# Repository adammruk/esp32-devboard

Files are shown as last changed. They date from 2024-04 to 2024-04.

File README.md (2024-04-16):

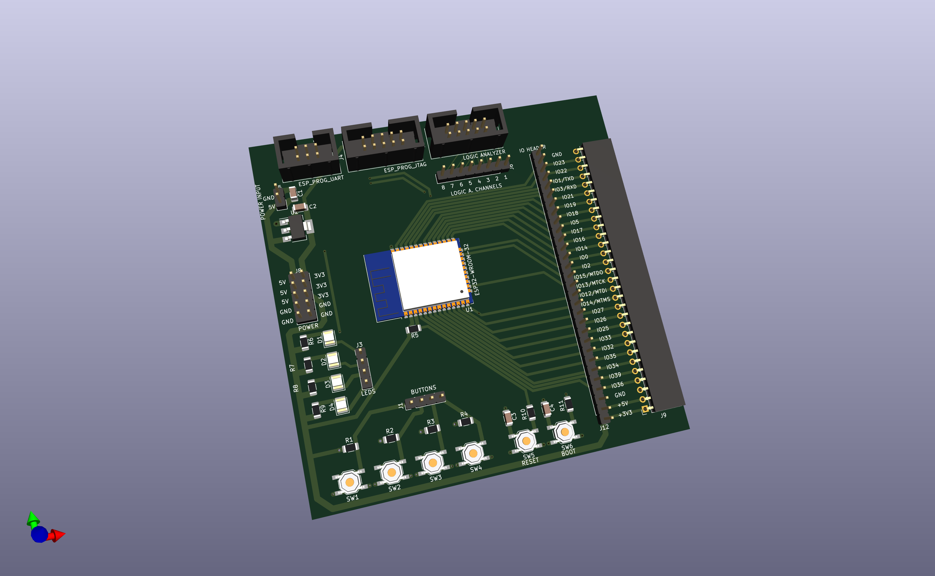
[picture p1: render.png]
ESP32 Development Board


# ESP32 Development Board

## Why a new development board?

Currently, there are many different development boards for ESP32 available on the market. I have also been using various different ones - ESP32-Cam, ESP32 WROOM, ESP32 WROOM on a board with buttons, MicroUSB port, and GPIO ports, ESP32 module with an LCD display, etc. Every board has some nice features, but overall I have always been missing the things that I believe a dev board should have:

- easy access to GPIO; most of the boards have a really inconvenient access to GPIO pins, making it harder to connect/disconnect cables
- properly described microcontroller pins, especially GPIO. This is the thing that widely used boards do the worst. Instead of using real pin descriptions, most of them use Arduino-based numbers (like 1, 2, 3 instead of GPIO01, GPIO02, etc). It may not be a big deal while using Arduino, but it's really problematic when using ESP-IDF
- easy to connect a logic analyzer or oscilloscope to GPIO. If not using a breadboard, it's complicated to connect two cables to one GPIO
- dedicated port for JTAG and serial port
- a few buttons and LEDs for generic purposes
- LOTS of power and GND pins

This made me think to create a new development board to address all of those issues.

## Features

1. Easy access to GPIO boards with clear descriptions
2. Designed to work with popular Saleae logic analyzer but compatible with all logic analyzers or oscilloscopes
3. Compatible with [ESP-Prog](https://docs.espressif.com/projects/espressif-esp-iot-solution/en/latest/hw-reference/ESP-Prog_guide.html) JTAG and UART
4. General purpose buttons and LEDs
5. Easily accessible power pins (5V, 3.3V and GND) on both sides of the board

## Opening project
Just open projects files in KiCad. Every symbol and footpring should be automatically imported.

## Contributing

Just create a Pull Request with your changes, make sure to describe and explain the changes you would like to make. If you'll encounter any errors, [feel free to create an issue.](https://github.com/adammruk/esp32-devboard/issues)

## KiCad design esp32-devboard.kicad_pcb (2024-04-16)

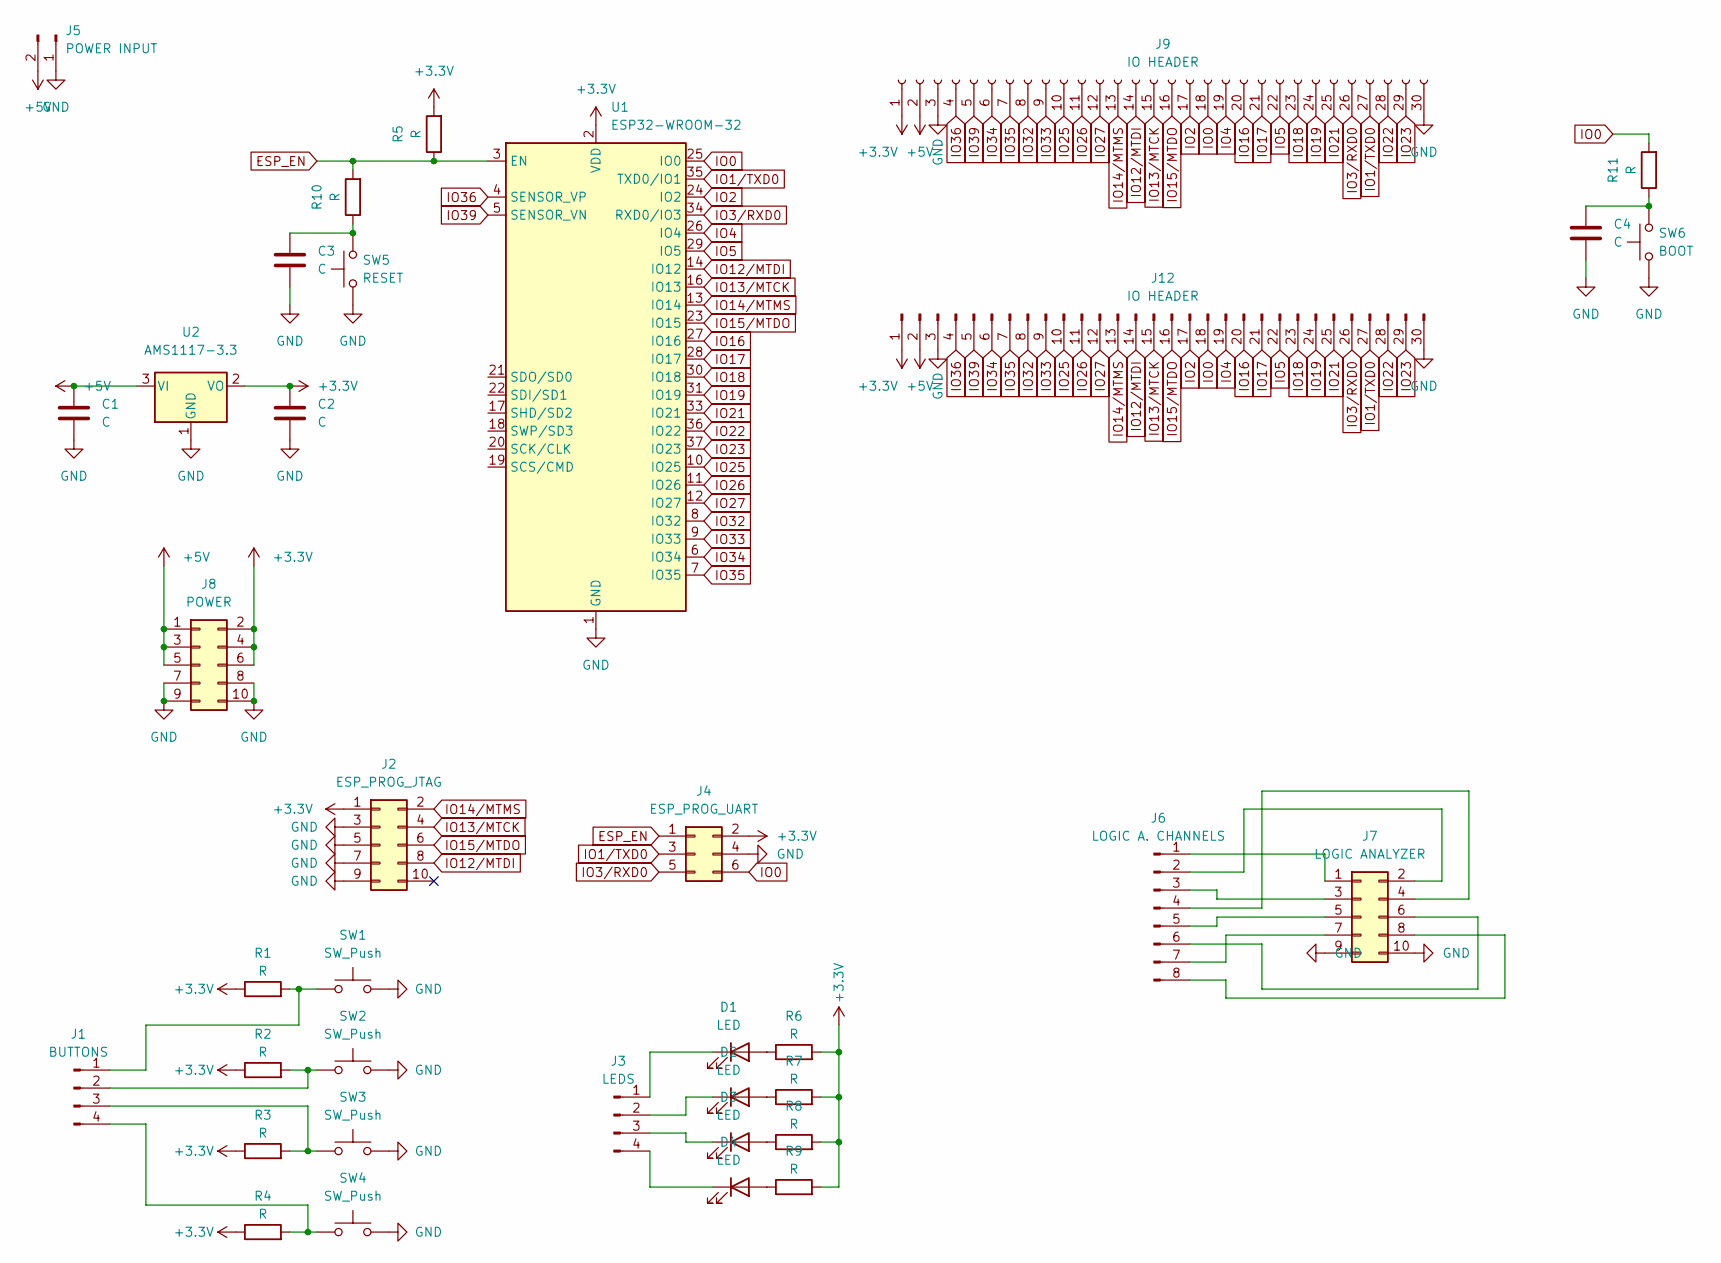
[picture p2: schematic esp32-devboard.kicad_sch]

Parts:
C1, C2, C3, C4: C; C_1206_3216Metric
D1, D2, D3, D4: LED; LED_1210_3225Metric
J1: BUTTONS; PinHeader_1x04_P2.54mm_Vertical
J2: ESP_PROG_JTAG; IDC-Header_2x05_P2.54mm_Vertical
J3: LEDS; PinHeader_1x04_P2.54mm_Vertical
J4: ESP_PROG_UART; IDC-Header_2x03_P2.54mm_Vertical
J5: POWER INPUT; PinHeader_1x02_P2.54mm_Vertical
J6: LOGIC A. CHANNELS; PinHeader_1x08_P2.54mm_Vertical
J7: LOGIC ANALYZER; IDC-Header_2x05_P2.54mm_Vertical
J8: POWER; PinHeader_2x05_P2.54mm_Vertical
J9: IO HEADER; PinSocket_1x30_P2.54mm_Horizontal
J12: IO HEADER; PinHeader_1x30_P2.54mm_Vertical
R1, R2, R3, R4, R5, R6, R7, R8, R9, R10, R11: R; R_1206_3216Metric
SW1, SW2, SW3, SW4: SW_Push; SW_SPST_TL3342
SW5: RESET; SW_SPST_TL3342
SW6: BOOT; SW_SPST_TL3342
U1: ESP32-WROOM-32
U2: AMS1117-3.3; SOT-223-3_TabPin2

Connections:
+3V3: C2.2, J2.1, J4.2, J8.2, J8.4, J8.6, J9.1, J12.1, R1.1, R2.1, R3.1, R4.1, R5.2, R6.2, R7.2, R8.2, R9.2, U1.2 (VDD), U2.2 (VO)
+5V: C1.2, J5.2, J8.1, J8.3, J8.5, J9.2, J12.2, U2.3 (VI)
ESP_EN: J4.1, R5.1, R10.2, U1.3 (EN)
GND: C1.1, C2.1, C3.1, C4.1, J2.3, J2.5, J2.7, J2.9, J4.4, J5.1, J7.9, J7.10, J8.7, J8.8, J8.9, J8.10, J9.3, J9.30, J12.3, J12.30, SW1.2, SW2.2, SW3.2, SW4.2, SW5.1, SW6.1, U1.1 (GND), U1.15 (GND), U1.38 (GND), U1.39 (GND), U2.1 (GND)
IO0: J4.6, J9.18, J12.18, R11.2, U1.25 (IO0)
IO1/TXD0: J4.3, J9.27, J12.27, U1.35 (TXD0/IO1)
IO2: J9.17, J12.17, U1.24 (IO2)
IO3/RXD0: J4.5, J9.26, J12.26, U1.34 (RXD0/IO3)
IO4: J9.19, J12.19, U1.26 (IO4)
IO5: J9.22, J12.22, U1.29 (IO5)
IO12/MTDI: J2.8, J9.14, J12.14, U1.14 (IO12)
IO13/MTCK: J2.4, J9.15, J12.15, U1.16 (IO13)
IO14/MTMS: J2.2, J9.13, J12.13, U1.13 (IO14)
IO15/MTDO: J2.6, J9.16, J12.16, U1.23 (IO15)
IO16: J9.20, J12.20, U1.27 (IO16)
IO17: J9.21, J12.21, U1.28 (IO17)
IO18: J9.23, J12.23, U1.30 (IO18)
IO19: J9.24, J12.24, U1.31 (IO19)
IO21: J9.25, J12.25, U1.33 (IO21)
IO22: J9.28, J12.28, U1.36 (IO22)
IO23: J9.29, J12.29, U1.37 (IO23)
IO25: J9.10, J12.10, U1.10 (IO25)
IO26: J9.11, J12.11, U1.11 (IO26)
IO27: J9.12, J12.12, U1.12 (IO27)
IO32: J9.8, J12.8, U1.8 (IO32)
IO33: J9.9, J12.9, U1.9 (IO33)
IO34: J9.6, J12.6, U1.6 (IO34)
IO35: J9.7, J12.7, U1.7 (IO35)
IO36: J9.4, J12.4, U1.4 (SENSOR_VP)
IO39: J9.5, J12.5, U1.5 (SENSOR_VN)
unnamed: C3.2, R10.1, SW5.2
unnamed: C4.2, R11.1, SW6.2
unnamed: D1.2 (A), R6.1
unnamed: D1.1 (K), J3.1
unnamed: D2.2 (A), R7.1
unnamed: D2.1 (K), J3.2
unnamed: D3.2 (A), R8.1
unnamed: D3.1 (K), J3.3
unnamed: D4.2 (A), R9.1
unnamed: D4.1 (K), J3.4
unnamed: J1.1, R1.2, SW1.1
unnamed: J1.2, R2.2, SW2.1
unnamed: J1.3, R3.2, SW3.1
unnamed: J1.4, R4.2, SW4.1
unnamed: J6.1, J7.1
unnamed: J6.2, J7.2
unnamed: J6.3, J7.3
unnamed: J6.4, J7.4
unnamed: J6.5, J7.5
unnamed: J6.6, J7.6
unnamed: J6.7, J7.7
unnamed: J6.8, J7.8

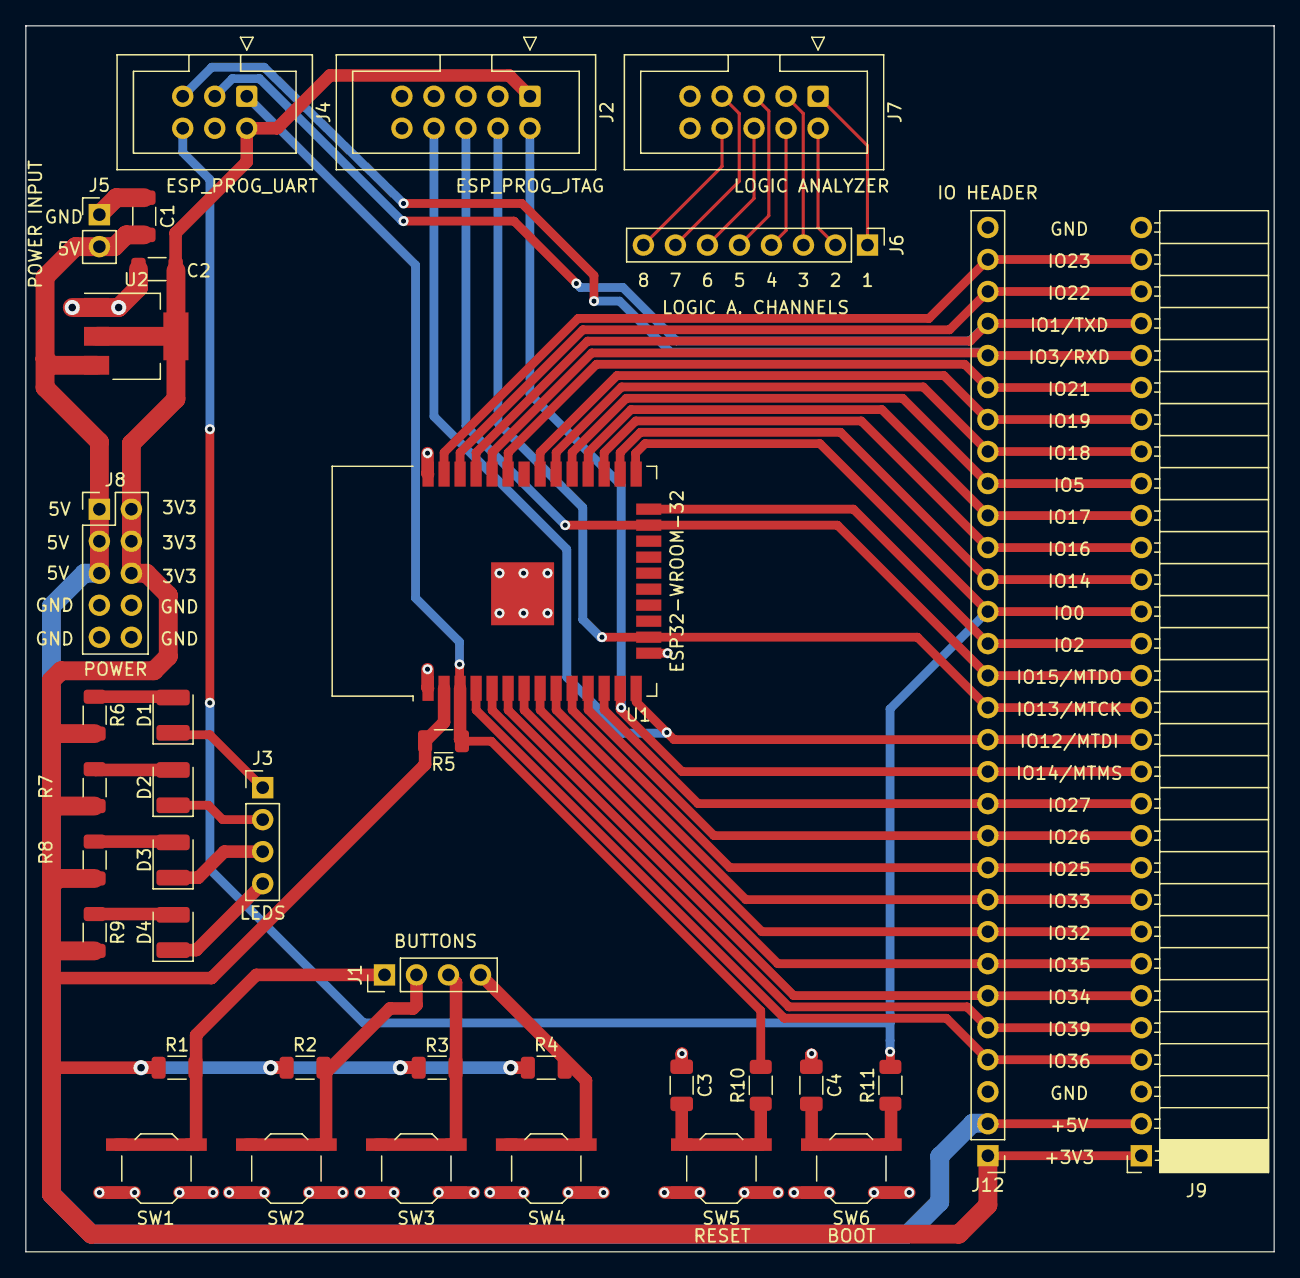
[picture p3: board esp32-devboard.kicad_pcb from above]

Board: 2 copper layers, 99.1 x 97.3 mm, 37 parts (0 on the bottom side), 52 nets.
